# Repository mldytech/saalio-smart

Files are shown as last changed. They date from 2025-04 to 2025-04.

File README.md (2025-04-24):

# saalio-smart (**work in progress**)

**Disclaimer: Use at your own risk, no guarantee or liability.** 

This project is an attempt to reverse engineer the saalio iontophoresis medical device. The procedure should be as minimally invasive as possible so that the functionality and especially safety of the device is not impaired in any way. \
The general motivation behind this is to track the therapy sessions so that they are not forgotten. It should also help to better understand the progress and success of the therapy.  \
\
The ultimate goal is to record all session data (duration, voltage, current, dc/ppm) into some kind of logging system. Two main logging options are currently offered:

1) Communication via. MQTT for use with e.g. HomeAssistant
2) Communication via. HTTP for use with InfluxDB and Grafana

*As a first step, and due to the lack of available analysis tools (e. g. an logic analyzer), **only the active status is logged for the time being**. An ESP32 is connected to the power source of the device so that it always starts automatically with a therapy session. This already provides basic functionality to track when therapy has taken place and is (imo) a huge advantage compared to taking notes manually.*

## Device hardware overview
[saalio-iontophoresis-device](https://www.saalmann-medical.de/iontophorese/saalio-iontophorese-geraet/)

## Specs

* VCC: 24V DC
* Max. Voltage for therapy: 58V
* Max. Current for therapy: 30mA
* DC and PPM
* PIC18F46K80

### 'Labeled' circuit board
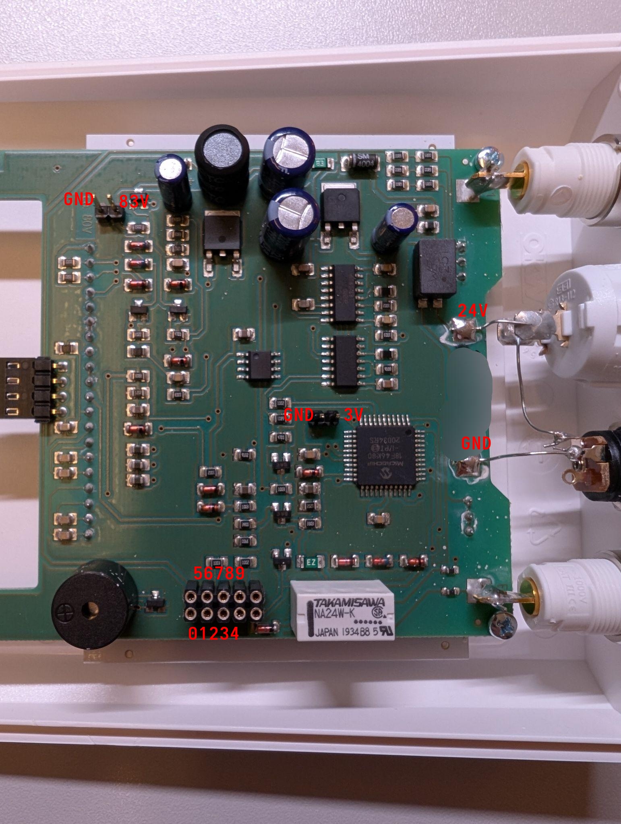
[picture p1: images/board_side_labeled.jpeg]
Board Side


### Modified board
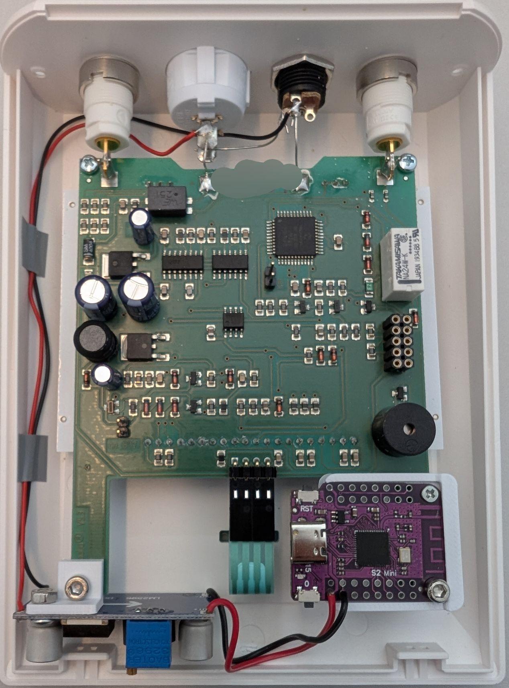
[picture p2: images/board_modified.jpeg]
Board modified


### The "Debug" Pin-Layout (WIP)
| Pin | 0  | 1  | 2  | 3  | 4  | 5  | 6  | 7  | 8  | 9  |
|-----|----|----|----|----|----|----|----|----|----|----|
| Function | GND | ? | ? | ? | ? | VCC (24V) | ? | ? | ? | ? |

### Realizations
* Although the 'Kal Pin' (next to the PIC) supplies 3v and is therefore predestined to power the esp, the slightest change in voltage causes the device to reboot. Presumably, the 'Kal Pin' - as the name intends - is used to calibrate / monitor the internal voltages which is why we can't connect anything here.
* Although pin 0 and 5 seem to provide VCC, the esp is connected directly to the input of the power supply. The main reason for this is the (still) lack of understanding of the circuit, which is why it is less invasive and more sensible from a safety point of view.

## Used Hardware
* [Wemos S2 Mini (ESP32)](https://www.wemos.cc/en/latest/s2/s2_mini.html)
* [LM2596S DC-DC step down module](https://www.az-delivery.de/products/lm2596s-dc-dc-step-down-modul-1)
* [3D-Printed mount for the LM2596](hardware/models/lm2596_mount.stl)
* [3D-Printed mount for the S2 Mini](hardware/models/s2mini_mount.stl), credits: [printables.com](https://www.printables.com/model/1121556-wemos-s2-mini-mount/files)

## Used Software
* PlatformIO with esp-idf, make sure to select USB-CDC (not UART) in `pio run -t menuconfig`

## Example graph of tracking usage in Grafana
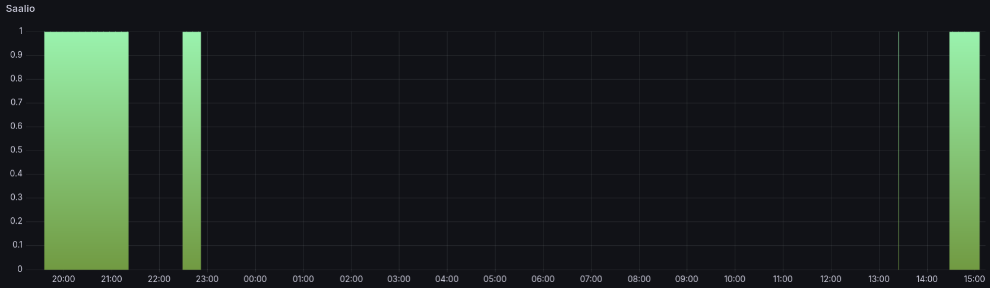
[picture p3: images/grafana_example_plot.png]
Grafana


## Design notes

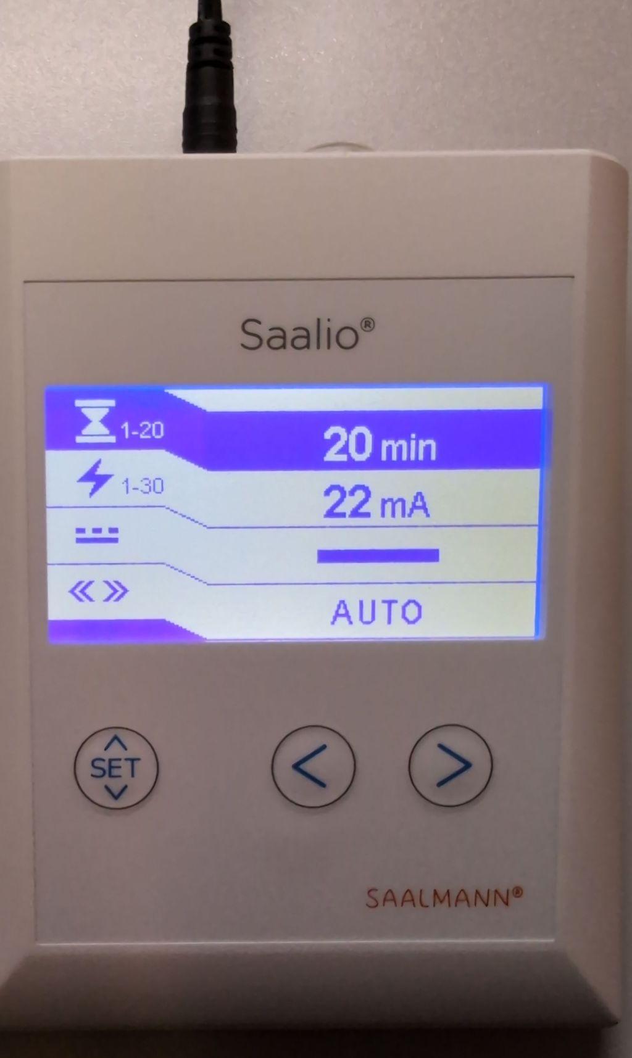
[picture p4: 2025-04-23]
images/device_front_on.jpeg

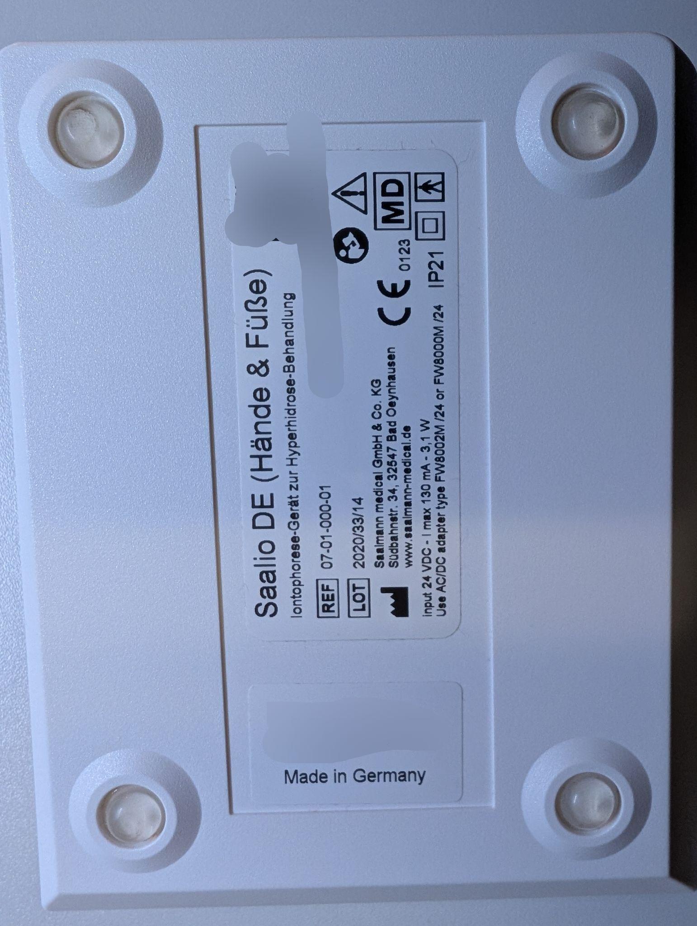
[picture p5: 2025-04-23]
images/device_back.jpeg

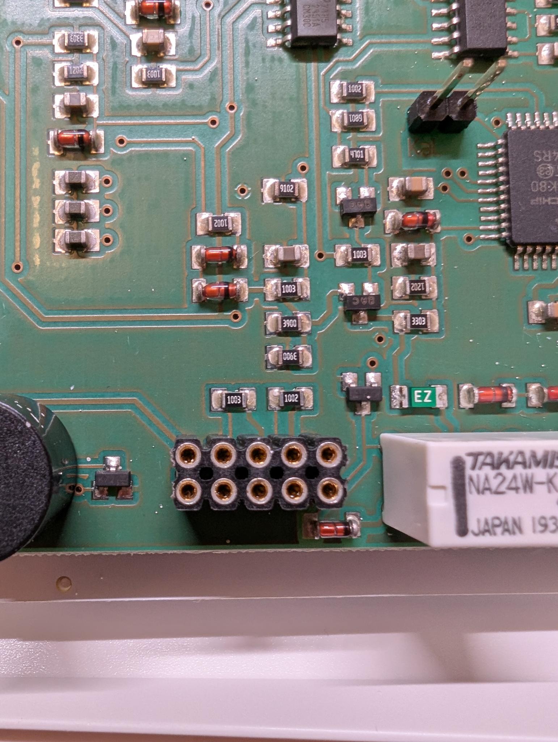
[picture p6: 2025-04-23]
images/pins_closeup.jpeg

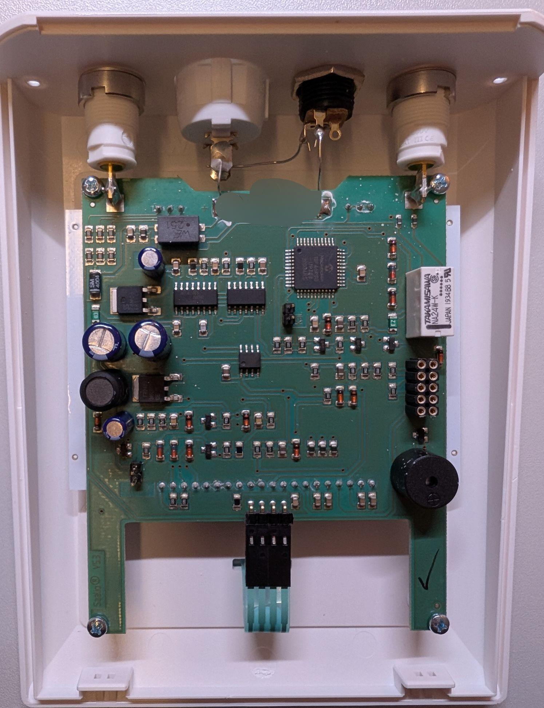
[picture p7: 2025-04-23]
images/board_full.jpeg

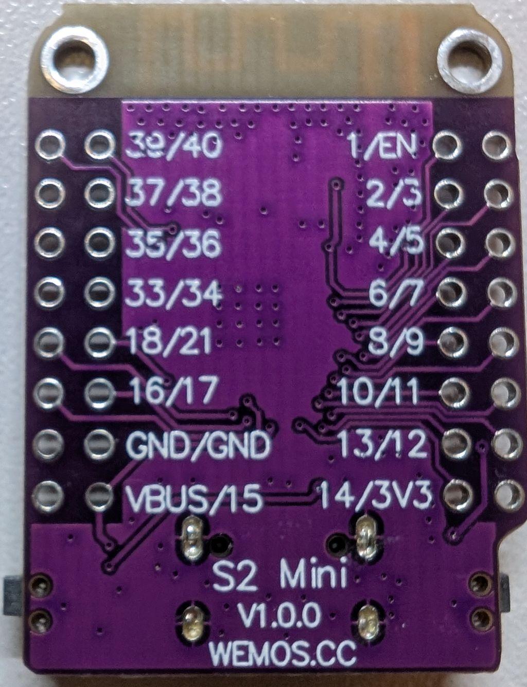
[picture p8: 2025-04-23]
images/s2mini_back.jpeg

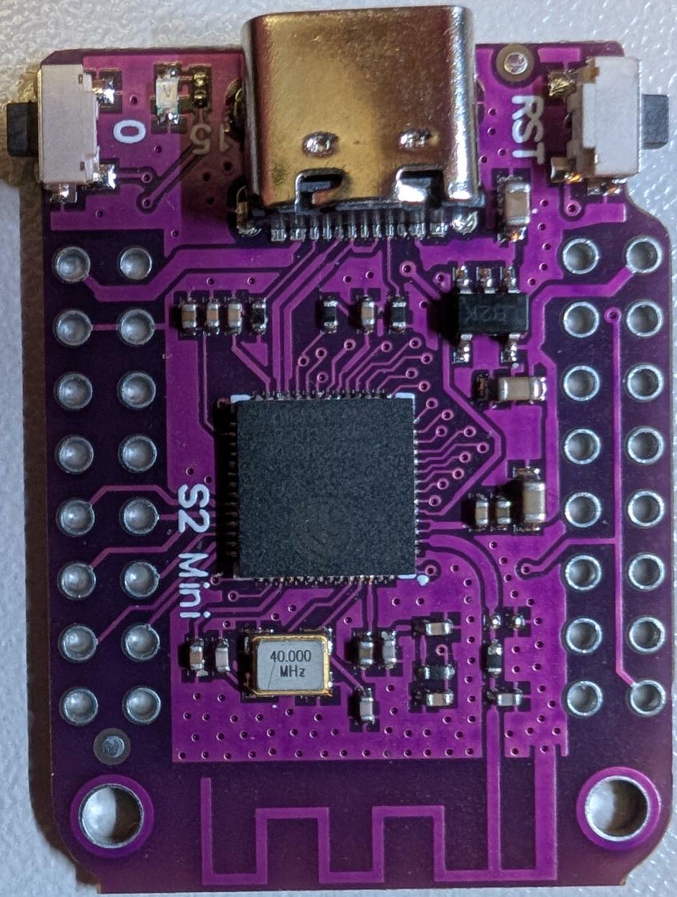
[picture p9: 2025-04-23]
images/s2mini_front.jpeg

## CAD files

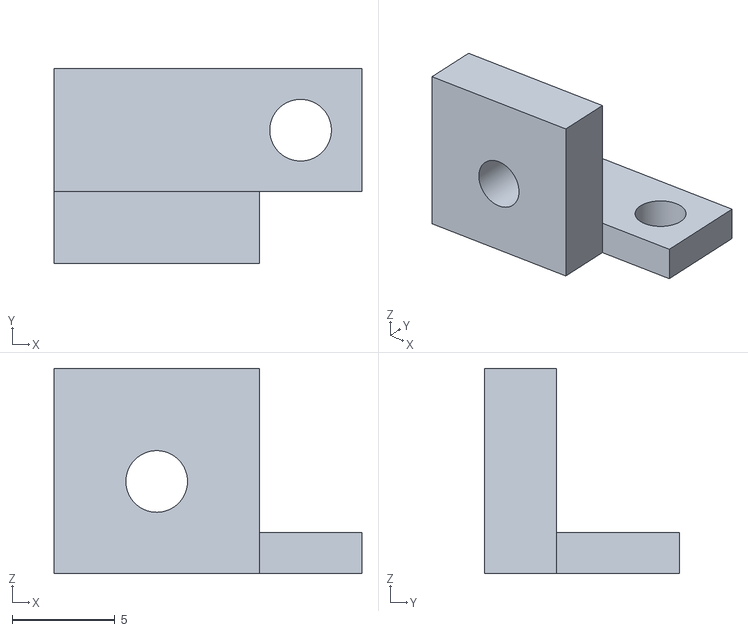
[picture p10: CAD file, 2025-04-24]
hardware/models/lm2596_mount.stl
15.0 x 9.50 x 10.0

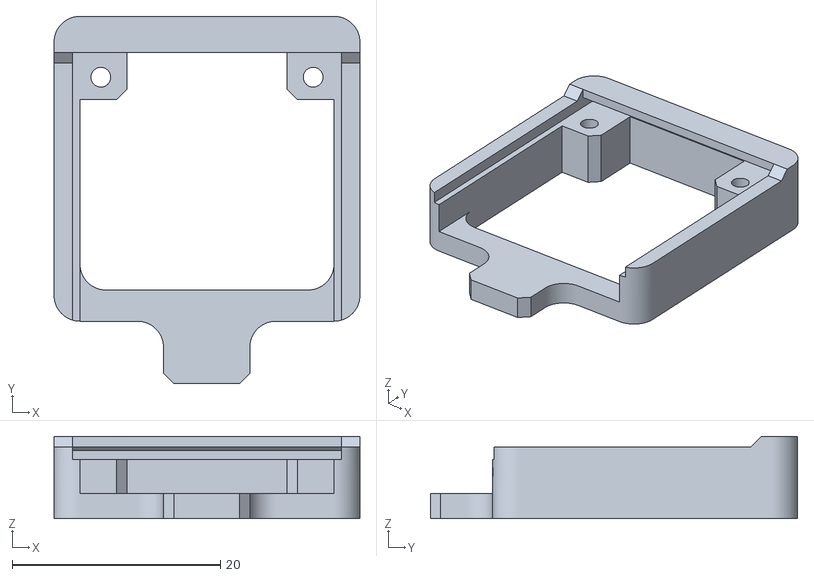
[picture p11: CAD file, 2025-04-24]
hardware/models/s2mini_mount.stl
29.4 x 35.3 x 7.90

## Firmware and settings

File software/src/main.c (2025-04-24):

#include <stdio.h>
#include <string.h>
#include <inttypes.h>
#include "sdkconfig.h"
#include "freertos/FreeRTOS.h"
#include "freertos/task.h"
#include "esp_chip_info.h"
#include "esp_flash.h"
#include "esp_system.h"

#include "esp_event.h"
#include "nvs_flash.h" //non volatile storage

#include "config.h"
#include <wifi.h>
#include <mqtt.h>
#include <influx.h>
#include <homeassistant.h>


void app_main(void)
{
    //Initialize NVS
    esp_err_t ret = nvs_flash_init();
    if (ret == ESP_ERR_NVS_NO_FREE_PAGES || ret == ESP_ERR_NVS_NEW_VERSION_FOUND) {
      ESP_ERROR_CHECK(nvs_flash_erase());
      ret = nvs_flash_init();
    }
    ESP_ERROR_CHECK(ret);
    
    wifi_init_sta();                        //initialize WiFi

    #ifdef SEND_TO_HOMEASSISTANT
    mqtt_app_start();                       //connect to mqtt broker

    //say hello to hass
    esp_mqtt_client_publish(client, "/saalio/keepalive", "Hello World", 0, 1, 0);
    send_discovery_message();
    update_switch_state("ON");
    #endif

    #ifdef SEND_TO_INFLUX
    //start a parallel task for sending the keepalive message to influxdb

    xTaskCreate(send_influx_keepalive, "send_keepalive", 2048, NULL, 5, NULL);
    #endif

    fflush(stdout);
}

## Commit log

2025-04-23 basic homeassistant functionality as a switch (will be changed to custom device later)
2025-04-23 different device board + uart (now using usb cdc)
2025-04-24 3d printed mounts for s2mini and lm2596
    [lm2596_mount.stl, s2mini_mount.stl]
2025-04-24 modified board
2025-04-24 modified pin table
2025-04-24 explained why pin 0/5 isn't used
